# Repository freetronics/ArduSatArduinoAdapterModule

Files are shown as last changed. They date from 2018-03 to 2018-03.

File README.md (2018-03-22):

Freetronics ArduSat Arduino Adapter Module
==========================================
Copyright 2012 Freetronics Pty Ltd   www.freetronics.com  

CubeSat-compatible module that allows an Arduino or compatible board
to be plugged in upside down. All Arduino headers and CubeSat bus
headers are broken out to allow you to quickly hook any Arduino
model with Uno-compatible headers into a satellite stack.

Includes prototyping area to add your own parts.

Features:

 * CubeSat bus fully broken out, with CubeSat 5V and 3.3V duplicated.
 * Jumpers to allow easy linkage of Arduino and CubeSat power rails.
 * 5V and 3.3V "power on" LEDs.
 * Reset button connected to Arduino reset pin.
 * Parts overlay on both the top and the bottom so you can see what you
   are connecting without having to keep turning the board over.
 * Prototyping area.
 * Gold-plated PCB surface.

More information is available at:

  http://www.freetronics.com.au/asaam

INSTALLATION
------------
The design is saved as an EAGLE project. EAGLE PCB design software is
available from www.cadsoftusa.com free for non-commercial use. To use
this project download it and place the directory containing these files
into the "eagle" directory on your computer. Then open EAGLE and
navigate to Projects -> eagle -> ArduSatArduinoAdapterModule.

DISTRIBUTION
------------
The specific terms of distribution of this project are governed by the
license referenced below.

LICENSE
-------
Licensed under the TAPR Open Hardware License (www.tapr.org/OHL).
The "license" folder within this repository also contains a copy of
this license in plain text format.

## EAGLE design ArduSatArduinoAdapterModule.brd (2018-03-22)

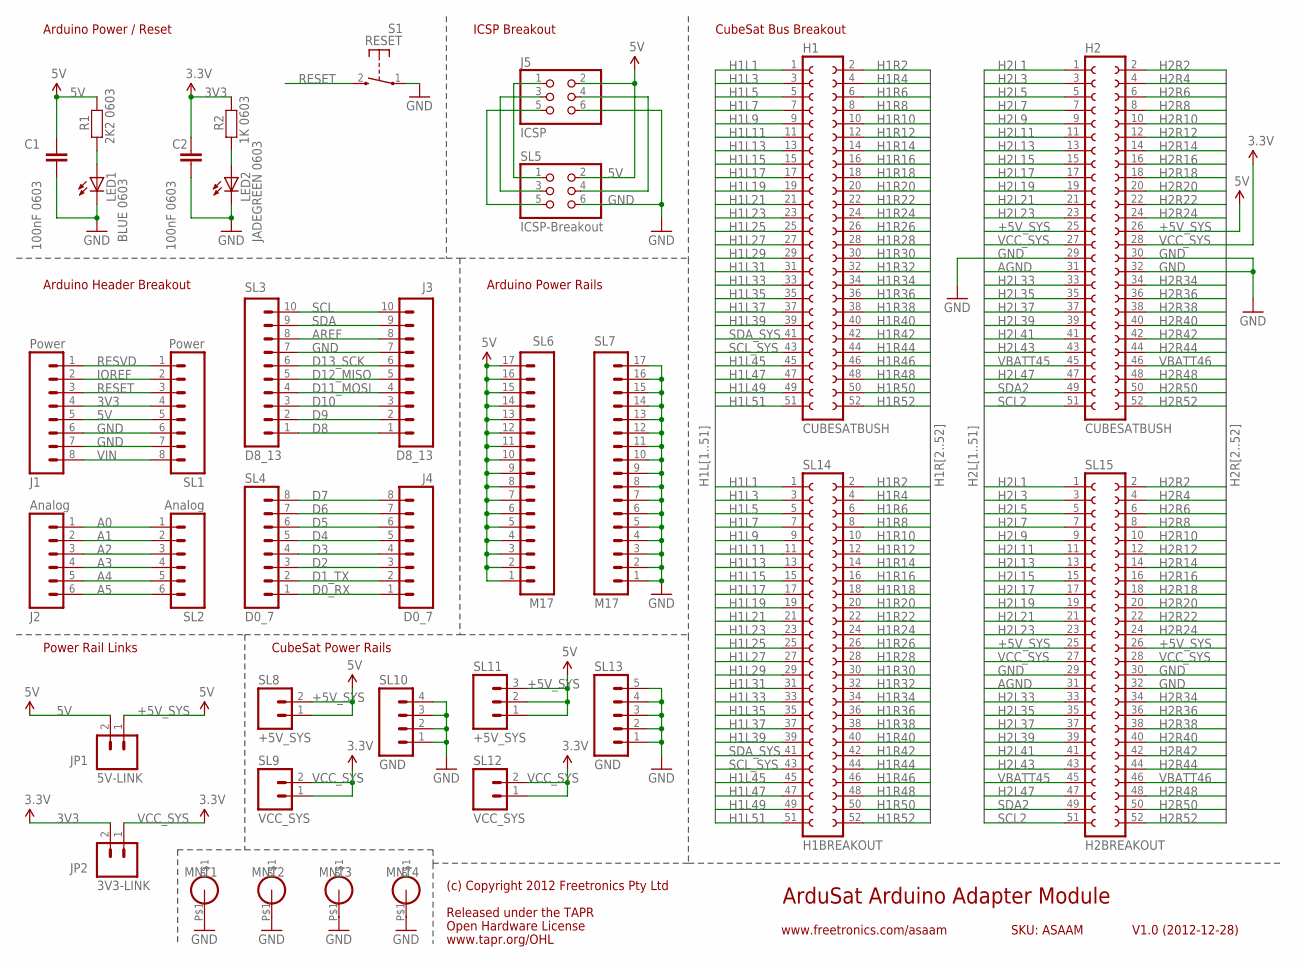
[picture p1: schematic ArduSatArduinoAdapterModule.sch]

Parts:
C1, C2: 100nF 0603; 0603
H1, H2: CUBESATBUSH; CUBESATBUS
J1: Power; 1X08
J2: Analog; 1X06
J3: D8_13; 1X10
J4: D0_7; 1X08
J5: ICSP; 2X03PTH
JP1: 5V-LINK; 1X02
JP2: 3V3-LINK; 1X02
LED1: BLUE 0603; LED-0603
LED2: JADEGREEN 0603; LED-0603
MNT1, MNT2, MNT3, MNT4: HOLE3.2MM; HOLE32
R1: 2K2 0603; 0603
R2: 1K 0603; 0603
S1: RESET; TACTILE_SWITCH_SMD_2PIN_TINY
SL1: Power; 1X08
SL2: Analog; 1X06
SL3: D8_13; 1X10
SL4: D0_7; 1X08
SL5: ICSP-Breakout; 2X03PTH
SL6, SL7: M17; 1X17
SL8: +5V_SYS; 1X02
SL9, SL12: VCC_SYS; 1X02
SL10: GND; 1X04
SL11: +5V_SYS; 1X03
SL13: GND; 1X05
SL14: H1BREAKOUT; CUBESATBUS
SL15: H2BREAKOUT; CUBESATBUS

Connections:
3V3: C2.1, J1.4, JP2.2, R2.1, SL1.4
5V: C1.1, J1.5, J5.2, JP1.2, R1.1, SL1.5, SL5.2, SL6.1, SL6.2, SL6.3, SL6.4, SL6.5, SL6.6, SL6.7, SL6.8, SL6.9, SL6.10, SL6.11, SL6.12, SL6.13, SL6.14, SL6.15, SL6.16, SL6.17
+5V_SYS: H2.25, H2.26, JP1.1, SL8.1, SL8.2, SL11.1, SL11.2, SL11.3, SL15.25, SL15.26
A0: J2.1, SL2.1
A1: J2.2, SL2.2
A2: J2.3, SL2.3
A3: J2.4, SL2.4
A4: J2.5, SL2.5
A5: J2.6, SL2.6
AGND: H2.31, SL15.31
AREF: J3.8, SL3.8
D0_RX: J4.1, SL4.1
D1_TX: J4.2, SL4.2
D2: J4.3, SL4.3
D3: J4.4, SL4.4
D4: J4.5, SL4.5
D5: J4.6, SL4.6
D6: J4.7, SL4.7
D7: J4.8, SL4.8
D8: J3.1, SL3.1
D9: J3.2, SL3.2
D10: J3.3, SL3.3
D11_MOSI: J3.4, SL3.4
D12_MISO: J3.5, SL3.5
D13_SCK: J3.6, SL3.6
GND: C1.2, C2.2, H2.29, H2.30, H2.32, J1.6, J1.7, J3.7, J5.6, LED1.C, LED2.C, MNT1.P$1, MNT2.P$1, MNT3.P$1, MNT4.P$1, S1.1, SL1.6, SL1.7, SL3.7, SL5.6, SL7.1, SL7.2, SL7.3, SL7.4, SL7.5, SL7.6, SL7.7, SL7.8, SL7.9, SL7.10, SL7.11, SL7.12, SL7.13, SL7.14, SL7.15, SL7.16, SL7.17, SL10.1, SL10.2, SL10.3, SL10.4, SL13.1, SL13.2, SL13.3, SL13.4, SL13.5, SL15.29, SL15.30, SL15.32
H1L1: H1.1, SL14.1
H1L3: H1.3, SL14.3
H1L5: H1.5, SL14.5
H1L7: H1.7, SL14.7
H1L9: H1.9, SL14.9
H1L11: H1.11, SL14.11
H1L13: H1.13, SL14.13
H1L15: H1.15, SL14.15
H1L17: H1.17, SL14.17
H1L19: H1.19, SL14.19
H1L21: H1.21, SL14.21
H1L23: H1.23, SL14.23
H1L25: H1.25, SL14.25
H1L27: H1.27, SL14.27
H1L29: H1.29, SL14.29
H1L31: H1.31, SL14.31
H1L33: H1.33, SL14.33
H1L35: H1.35, SL14.35
H1L37: H1.37, SL14.37
H1L39: H1.39, SL14.39
H1L45: H1.45, SL14.45
H1L47: H1.47, SL14.47
H1L49: H1.49, SL14.49
H1L51: H1.51, SL14.51
H1R2: H1.2, SL14.2
H1R4: H1.4, SL14.4
H1R6: H1.6, SL14.6
H1R8: H1.8, SL14.8
H1R10: H1.10, SL14.10
H1R12: H1.12, SL14.12
H1R14: H1.14, SL14.14
H1R16: H1.16, SL14.16
H1R18: H1.18, SL14.18
H1R20: H1.20, SL14.20
H1R22: H1.22, SL14.22
H1R24: H1.24, SL14.24
H1R26: H1.26, SL14.26
H1R28: H1.28, SL14.28
H1R30: H1.30, SL14.30
H1R32: H1.32, SL14.32
H1R34: H1.34, SL14.34
H1R36: H1.36, SL14.36
H1R38: H1.38, SL14.38
H1R40: H1.40, SL14.40
H1R42: H1.42, SL14.42
H1R44: H1.44, SL14.44
H1R46: H1.46, SL14.46
H1R48: H1.48, SL14.48
H1R50: H1.50, SL14.50
H1R52: H1.52, SL14.52
H2L1: H2.1, SL15.1
H2L3: H2.3, SL15.3
H2L5: H2.5, SL15.5
H2L7: H2.7, SL15.7
H2L9: H2.9, SL15.9
H2L11: H2.11, SL15.11
H2L13: H2.13, SL15.13
H2L15: H2.15, SL15.15
H2L17: H2.17, SL15.17
H2L19: H2.19, SL15.19
H2L21: H2.21, SL15.21
H2L23: H2.23, SL15.23
H2L33: H2.33, SL15.33
H2L35: H2.35, SL15.35
H2L37: H2.37, SL15.37
H2L39: H2.39, SL15.39
H2L41: H2.41, SL15.41
H2L43: H2.43, SL15.43
H2L47: H2.47, SL15.47
H2R2: H2.2, SL15.2
H2R4: H2.4, SL15.4
H2R6: H2.6, SL15.6
H2R8: H2.8, SL15.8
H2R10: H2.10, SL15.10
H2R12: H2.12, SL15.12
H2R14: H2.14, SL15.14
H2R16: H2.16, SL15.16
H2R18: H2.18, SL15.18
H2R20: H2.20, SL15.20
H2R22: H2.22, SL15.22
H2R24: H2.24, SL15.24
H2R34: H2.34, SL15.34
H2R36: H2.36, SL15.36
H2R38: H2.38, SL15.38
H2R40: H2.40, SL15.40
H2R42: H2.42, SL15.42
H2R44: H2.44, SL15.44
H2R48: H2.48, SL15.48
H2R50: H2.50, SL15.50
H2R52: H2.52, SL15.52
IOREF: J1.2, SL1.2
unnamed: LED2.A, R2.2
unnamed: LED1.A, R1.2
unnamed: J5.4, SL5.4
unnamed: J5.1, SL5.1
unnamed: J5.3, SL5.3
unnamed: J5.5, SL5.5
RESET: J1.3, S1.2 (S), SL1.3
RESVD: J1.1, SL1.1
SCL: J3.10, SL3.10
SCL2: H2.51, SL15.51
SCL_SYS: H1.43, SL14.43
SDA: J3.9, SL3.9
SDA2: H2.49, SL15.49
SDA_SYS: H1.41, SL14.41
VBATT45: H2.45, SL15.45
VBATT46: H2.46, SL15.46
VCC_SYS: H2.27, H2.28, JP2.1, SL9.1, SL9.2, SL12.1, SL12.2, SL15.27, SL15.28
VIN: J1.8, SL1.8

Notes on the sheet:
ArduSat Arduino Adapter Module
V1.0 (2012-12-28)
www.freetronics.com/asaam
SKU: ASAAM
CubeSat Bus Breakout
Released under the TAPR
Open Hardware License
www.tapr.org/OHL
(c) Copyright 2012 Freetronics Pty Ltd
Arduino Power / Reset
Arduino Header Breakout
Power Rail Links
CubeSat Power Rails
ICSP Breakout
Arduino Power Rails

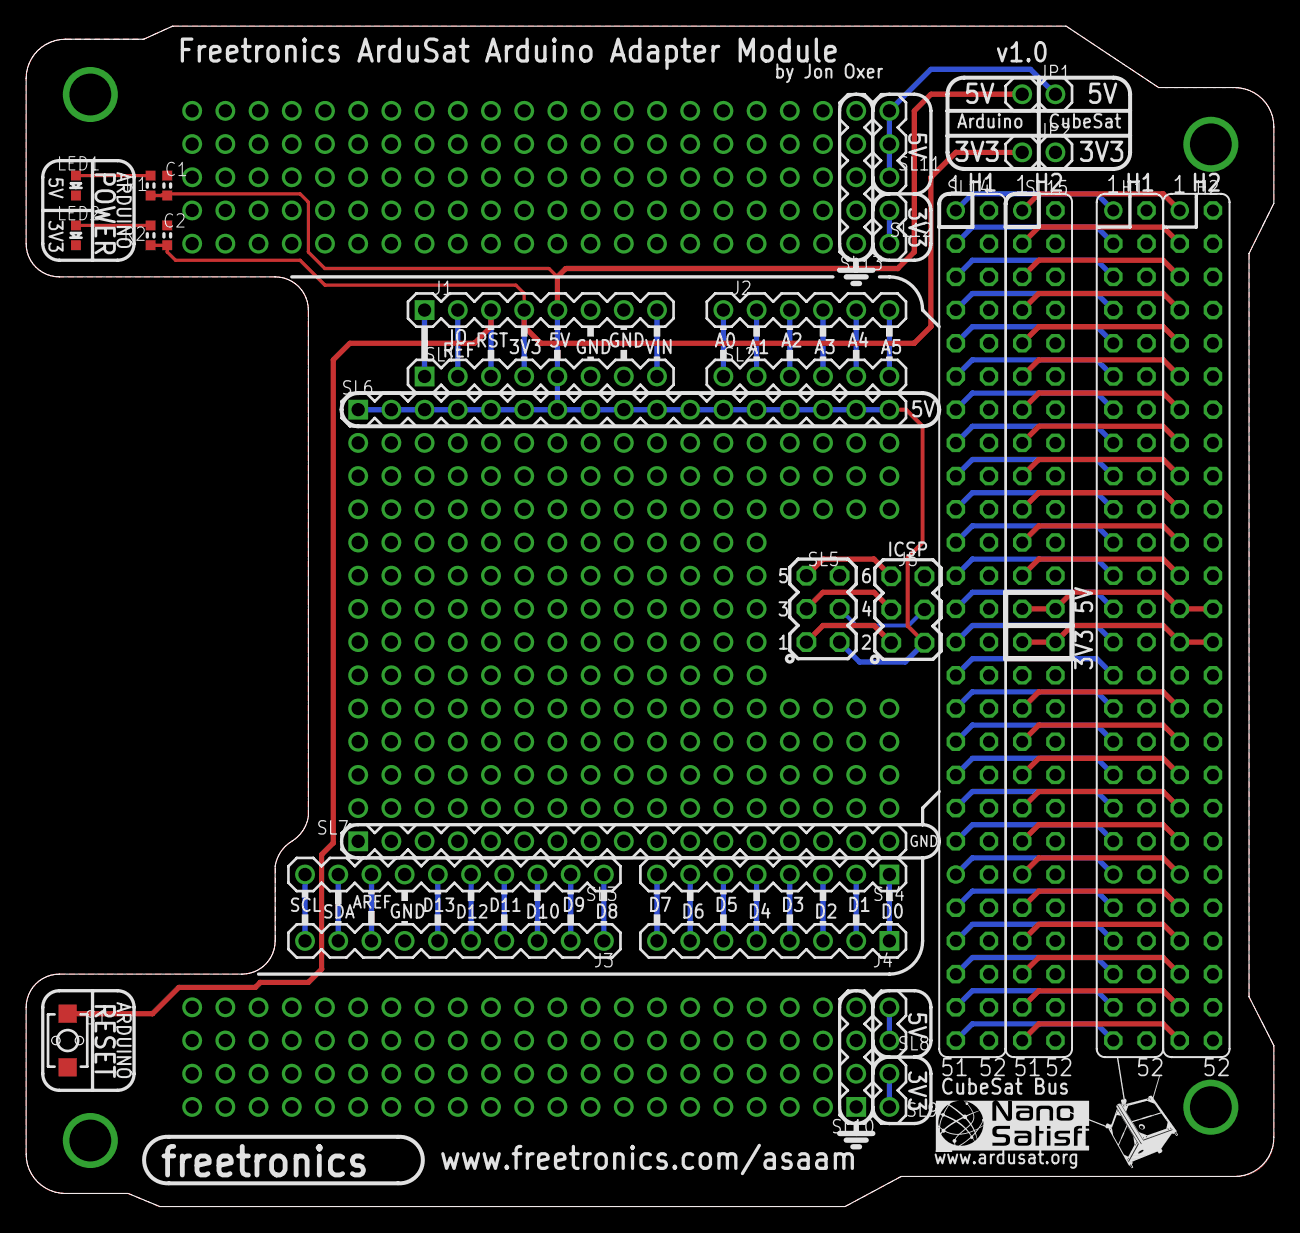
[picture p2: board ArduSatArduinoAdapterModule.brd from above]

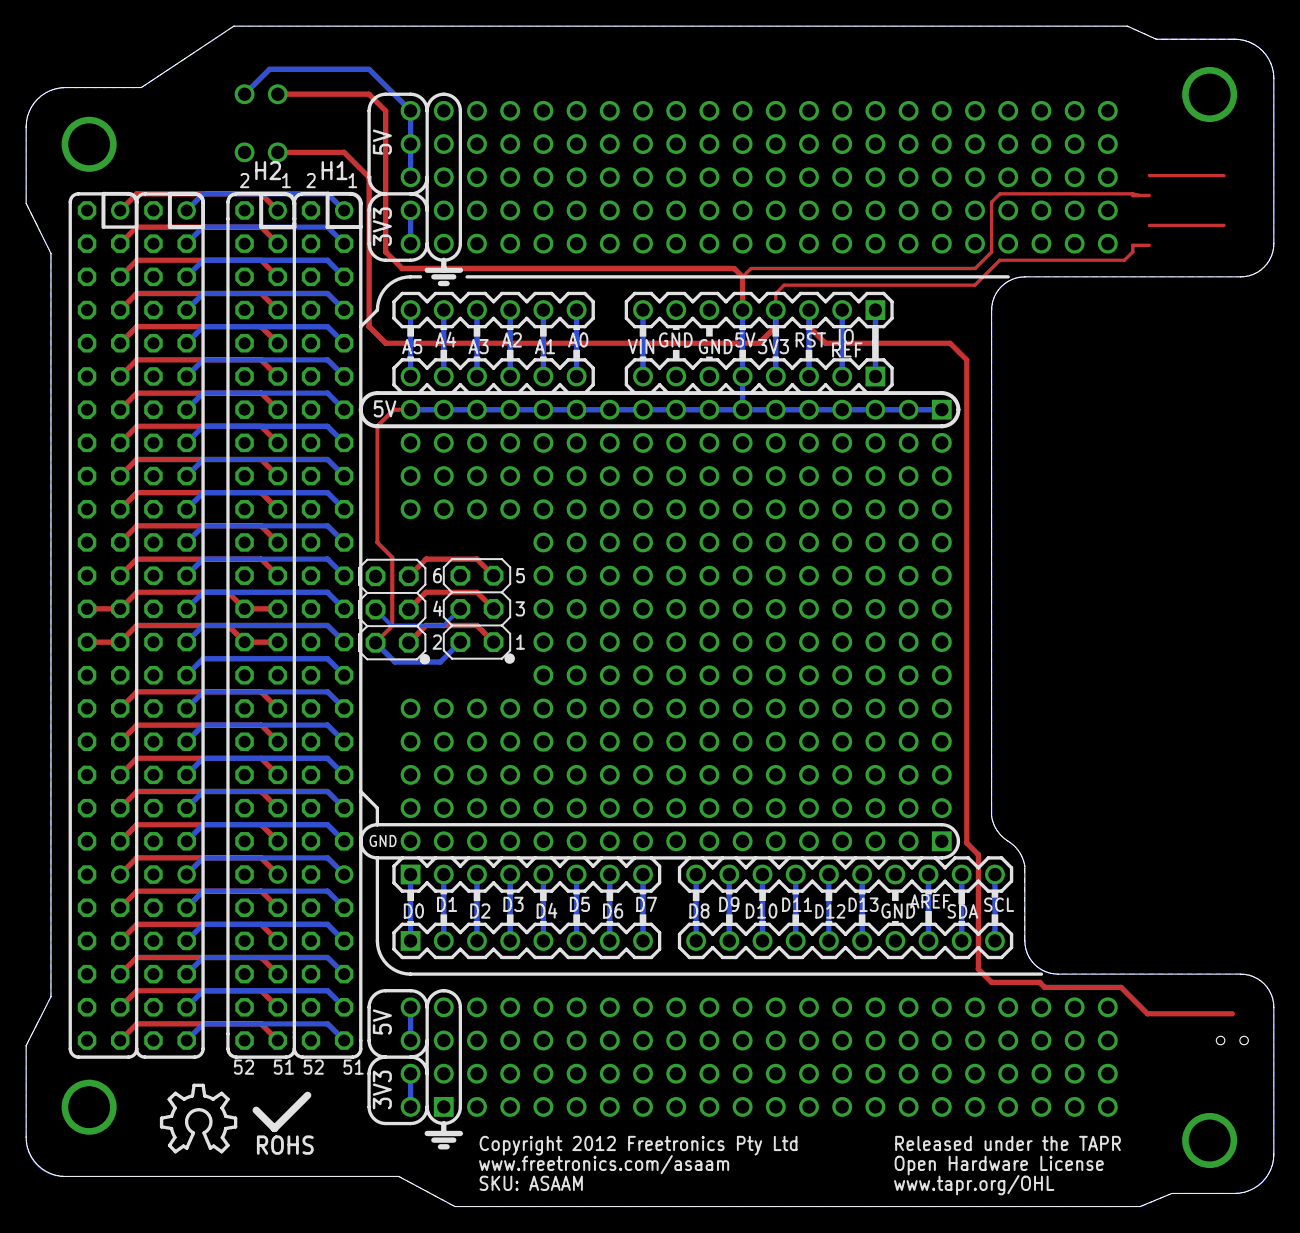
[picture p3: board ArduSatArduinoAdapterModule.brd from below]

Board: 4 copper layers, 95.5 x 90.3 mm, 36 parts (3 on the bottom side), 135 nets.

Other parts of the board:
U$5: OSHW_10X200_NOTEXT

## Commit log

2012-12-11 Initial project import
    [ArduSatArduinoAdapterModule.brd, ArduSatArduinoAdapterModule.sch]
2012-12-19 Switched to 4 layer PCB; completed all routing
    [ArduSatArduinoAdapterModule.brd, ArduSatArduinoAdapterModule.sch]
2012-12-28 Added grounded corner mount holes and relocated some traces to inner layers to minimise risk of shorts to mounting sleeves
    [ArduSatArduinoAdapterModule.brd, ArduSatArduinoAdapterModule.sch]
2018-03-22 Improved part label positions
    [ArduSatArduinoAdapterModule.brd]

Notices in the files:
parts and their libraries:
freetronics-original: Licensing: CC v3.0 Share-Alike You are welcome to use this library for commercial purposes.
